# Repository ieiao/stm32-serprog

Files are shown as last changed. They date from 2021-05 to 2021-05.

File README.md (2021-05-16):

# STM32-serprog

## 概述

本项目是flashrom工具serprog编程器的一种实现，参考了[dword1511/stm32-vserprog](https://github.com/dword1511/stm32-vserprog)中v3版本电路原理图，增加了电平转换芯片用来同时支持1.8V和3.3V的spi flash，可以直接使用该仓库中的代码，经测试可以正常工作，PCB效果图如下。

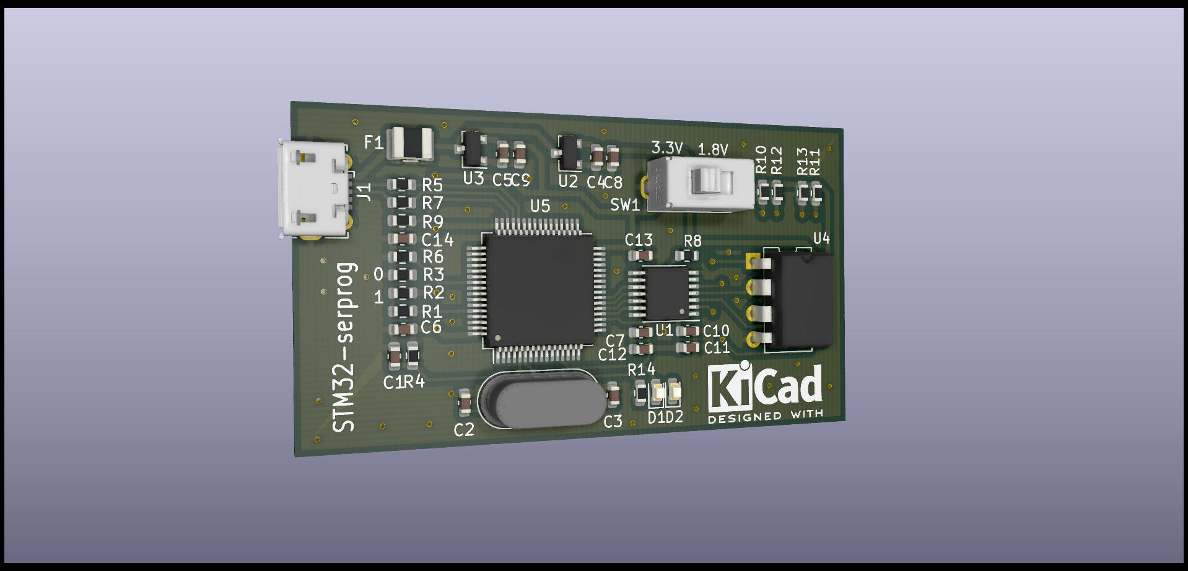
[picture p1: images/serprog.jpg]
stm32-serprog


## Changelog

* v0.2 (该版本未发板验证，不过原理图整体改动不大，应该没有问题)
    * 删除了多余的测试点
    * 将txs0108修改为txs0104/txb0104，节约成本

* v0.1
    * 第一个版本，已打板验证

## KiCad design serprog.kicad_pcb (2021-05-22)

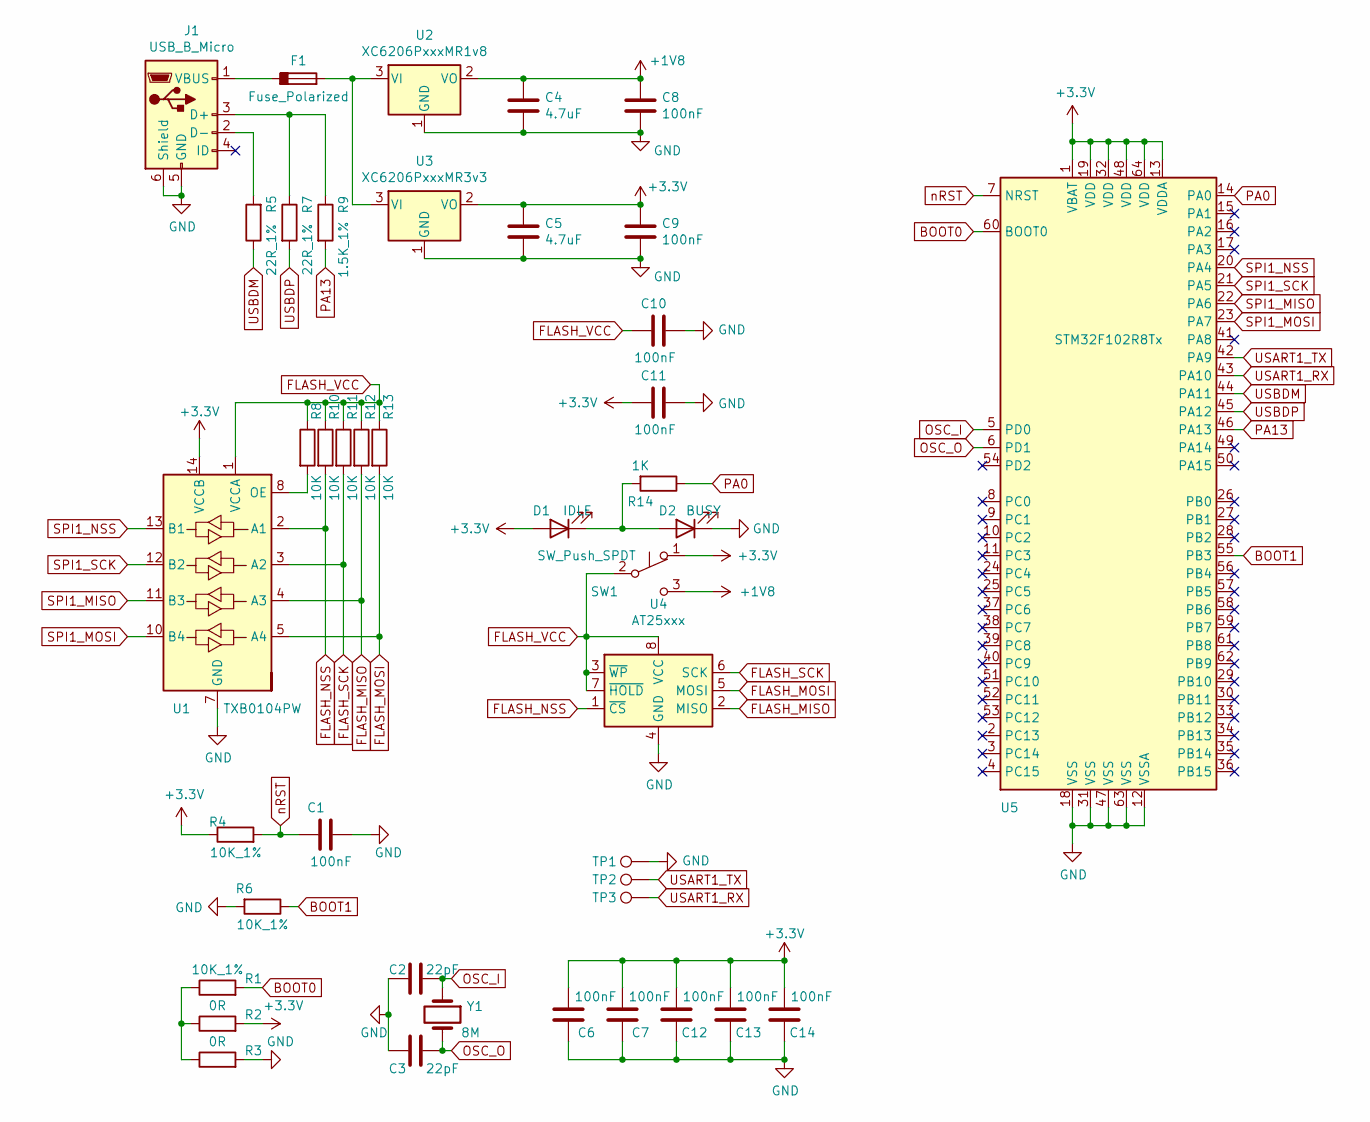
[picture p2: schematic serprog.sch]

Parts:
C1, C6, C7, C8, C9, C10, C11, C12, C13, C14: 100nF; C_0603_1608Metric
C2, C3: 22pF; C_0603_1608Metric
C4, C5: 4.7uF; C_0603_1608Metric
D1: IDLE; LED_0603_1608Metric
D2: BUSY; LED_0603_1608Metric
F1: Fuse_Polarized; Fuse_1210_3225Metric
J1: USB_B_Micro; USB_Micro-B_Molex-105017-0001
R1, R4, R6: 10K_1%; R_0603_1608Metric
R2, R3: 0R; R_0603_1608Metric
R5, R7: 22R_1%; R_0603_1608Metric
R8, R10, R11, R12, R13: 10K; R_0603_1608Metric
R9: 1.5K_1%; R_0603_1608Metric
R14: 1K; R_0603_1608Metric
SW1: SW_Push_SPDT; SW-DIP-3
TP1: GND; TestPoint_Pad_D1.0mm
TP2: TX; TestPoint_Pad_D1.0mm
TP3: RX; TestPoint_Pad_D1.0mm
U1: TXB0104PW; TSSOP-14_4.4x5mm_P0.65mm
U2: XC6206PxxxMR1v8; SOT-23
U3: XC6206PxxxMR3v3; SOT-23
U4: AT25xxx; DIP-8_W7.62mm
U5: STM32F102R8Tx; LQFP-64_10x10mm_P0.5mm
Y1: 8M; Crystal_HC49-4H_Vertical

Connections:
+1V8: C4.1, C8.1, SW1.3 (C), U2.2 (VO)
+3V3: C5.1, C6.1, C7.1, C9.1, C11.1, C12.1, C13.1, C14.1, D1.2 (A), R2.2, R4.1, SW1.1 (A), U1.14 (VCCB), U3.2 (VO), U5.1 (VBAT), U5.13 (VDDA), U5.19 (VDD), U5.32 (VDD), U5.48 (VDD), U5.64 (VDD)
BOOT0: R1.2, U5.60 (BOOT0)
BOOT1: R6.1, U5.55 (PB3)
FLASH_MISO: R12.2, U1.4 (A3), U4.2 (MISO)
FLASH_MOSI: R13.2, U1.5 (A4), U4.5 (MOSI)
FLASH_NSS: R10.2, U1.2 (A1), U4.1 (~CS)
FLASH_SCK: R11.2, U1.3 (A2), U4.6 (SCK)
FLASH_VCC: C10.1, R8.1, R10.1, R11.1, R12.1, R13.1, SW1.2 (B), U1.1 (VCCA), U4.3 (~WP), U4.7 (~HOLD), U4.8 (VCC)
GND: C1.2, C2.2, C3.2, C4.2, C5.2, C6.2, C7.2, C8.2, C9.2, C10.2, C11.2, C12.2, C13.2, C14.2, D2.1 (K), J1.5 (GND), J1.6 (Shield), R3.2, R6.2, TP1.1, U1.7 (GND), U2.1 (GND), U3.1 (GND), U4.4 (GND), U5.12 (VSSA), U5.18 (VSS), U5.31 (VSS), U5.47 (VSS), U5.63 (VSS); also elsewhere on the board
unnamed: D1.1 (K), D2.2 (A), R14.2
unnamed: F1.1, J1.1 (VBUS)
unnamed: F1.2, U2.3 (VI), U3.3 (VI)
unnamed: J1.2 (D-), R5.2
unnamed: J1.3 (D+), R7.1, R9.1
unnamed: R1.1, R2.1, R3.1
unnamed: R8.2, U1.8 (OE)
OSC_I: C2.1, U5.5 (PD0), Y1.1
OSC_O: C3.1, U5.6 (PD1), Y1.2
PA0: R14.1, U5.14 (PA0)
PA13: R9.2, U5.46 (PA13)
SPI1_MISO: U1.11 (B3), U5.22 (PA6)
SPI1_MOSI: U1.10 (B4), U5.23 (PA7)
SPI1_NSS: U1.13 (B1), U5.20 (PA4)
SPI1_SCK: U1.12 (B2), U5.21 (PA5)
USART1_RX: TP3.1, U5.43 (PA10); also elsewhere on the board
USART1_TX: TP2.1, U5.42 (PA9); also elsewhere on the board
USBDM: R5.1, U5.44 (PA11)
USBDP: R7.2, U5.45 (PA12)
nRST: C1.1, R4.2, U5.7 (NRST)

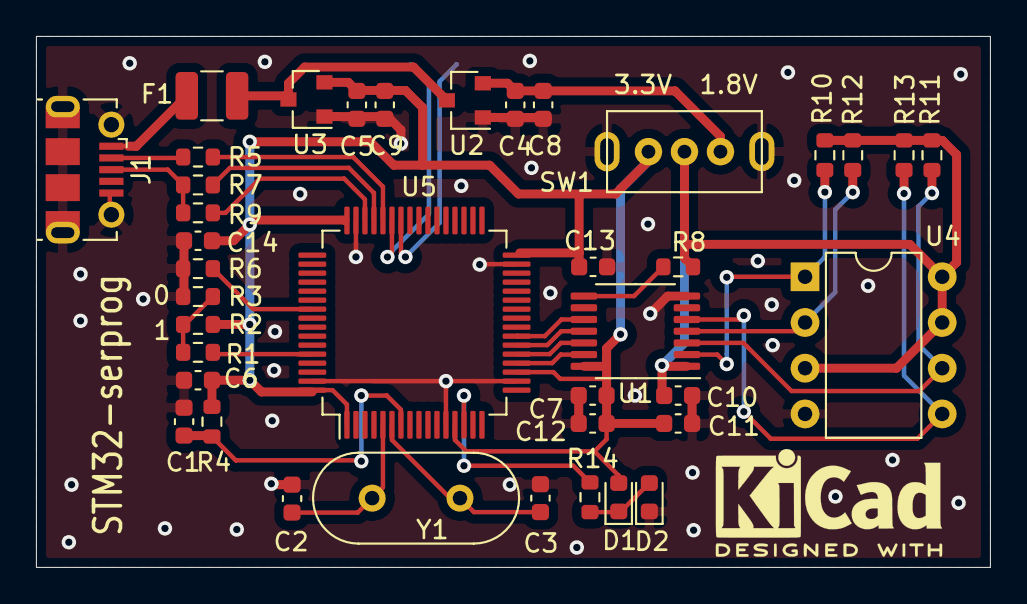
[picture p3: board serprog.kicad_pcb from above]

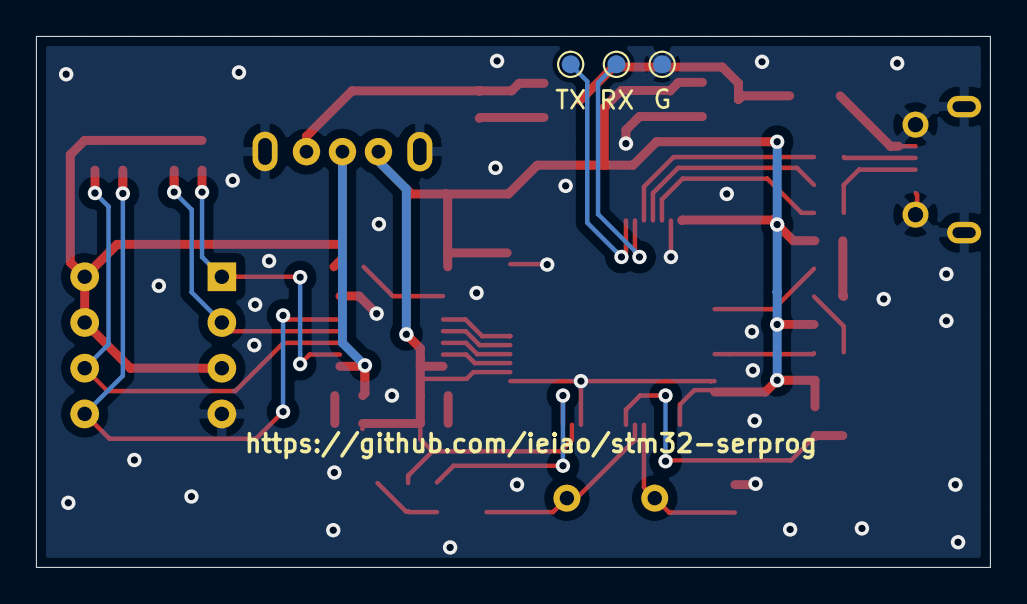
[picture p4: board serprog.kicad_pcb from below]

Board: 2 copper layers, 53.0 x 29.5 mm, 42 parts (3 on the bottom side), 30 nets.

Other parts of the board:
G: GND; TestPoint_Pad_D1.0mm
RX: RX; TestPoint_Pad_D1.0mm
TX: TX; TestPoint_Pad_D1.0mm

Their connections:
GND: G.1; also elsewhere on the board
USART1_RX: RX.1; also elsewhere on the board
USART1_TX: TX.1; also elsewhere on the board

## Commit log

2021-05-04 fist version
    [serprog.kicad_pcb, serprog.sch]
2021-05-22 fix url issue
    [serprog.kicad_pcb]
